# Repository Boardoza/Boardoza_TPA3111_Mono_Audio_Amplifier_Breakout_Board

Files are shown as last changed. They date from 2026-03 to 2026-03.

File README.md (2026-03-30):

# Boardoza TPA3111 Mono Audio Amplifier Breakout Board

The **Boardoza TPA3111 Mono Audio Amplifier Module** is a compact and efficient Class-D audio amplifier built around the **Texas Instruments TPA3111D1** chip. Designed to deliver up to **10W mono output power**, this board provides high-quality audio performance with minimal heat generation thanks to its high-efficiency architecture.

With a wide **8V to 28V DC input voltage range**, this amplifier module is compatible with a variety of power sources including DC adapters and battery systems. Screw terminal connections for power, audio input, and speaker output make installation quick and reliable. It is ideal for **DIY speaker builds, portable audio systems, embedded audio solutions, and custom sound projects** requiring compact and efficient amplification.

## [Click here to purchase!](https://www.ozdisan.com/ureticiler/boardoza)

| Front Side | Back Side |
|:---:|:---:|
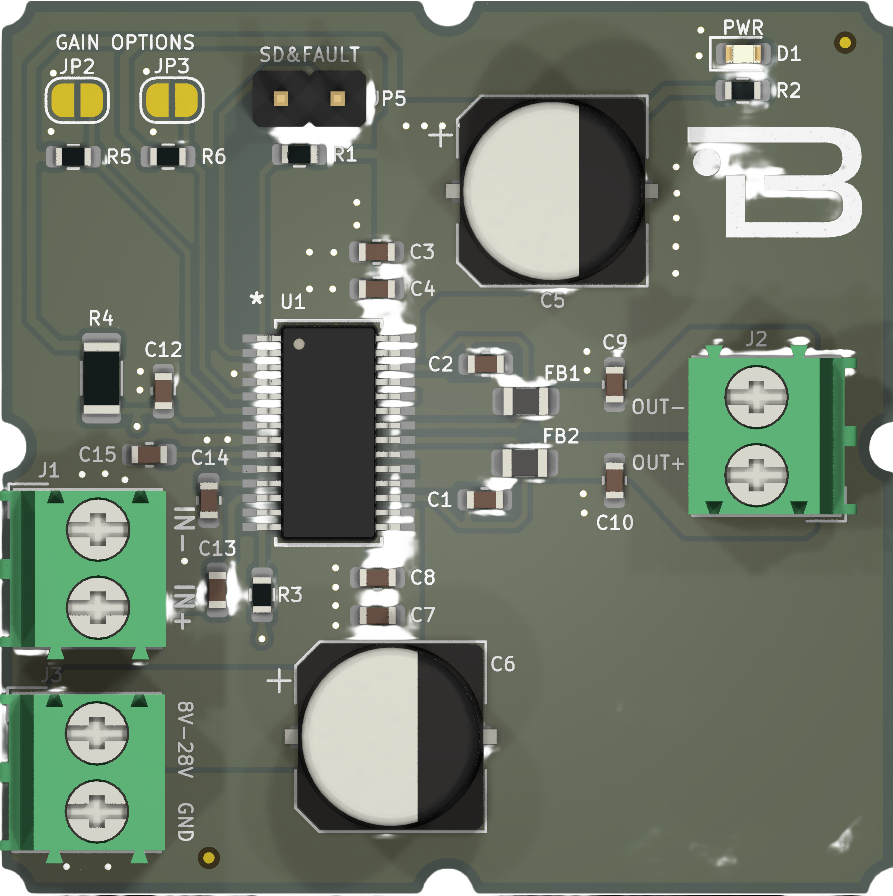
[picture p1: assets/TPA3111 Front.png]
TPA3111 Front
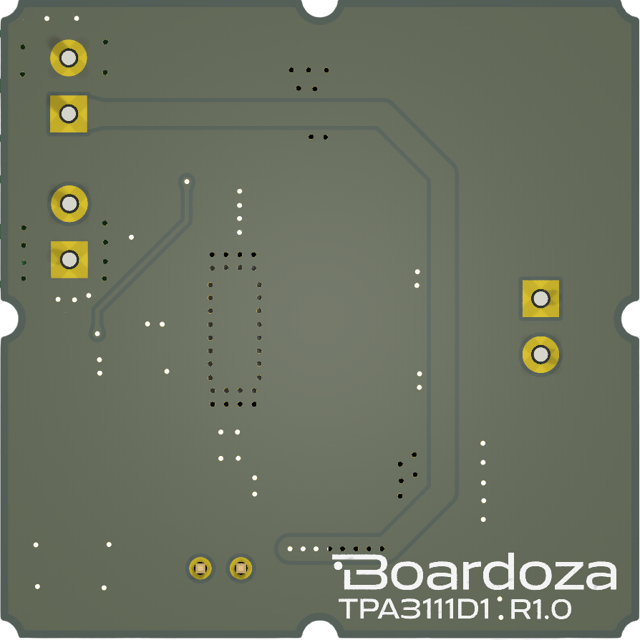
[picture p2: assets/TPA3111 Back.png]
TPA3111 Back
|  |  |

---

## Key Features

- **High-Efficiency Class-D Amplifier:** 310 khz Switching frequency provides clear and powerful mono audio output with minimal heat generation.
- **Wide Input Voltage Range:** Operates from 8V to 28V DC, compatible with various power sources.
- **Easy Connectivity:** Screw terminals for audio input, speaker output, and power connections.
- **Clean Audio Performance:** Integrated pop and click suppression for smooth startup and shutdown.
- **Built-in Protection Features:** Includes thermal shutdown and short-circuit protection for reliable operation.

---

## Technical Specifications

**Model:** TPA3111D1  
**Manufacturer:** Boardoza   
**Manufacturer IC:** Texas Instruments   
**Input Voltage:** 8V – 28V DC  
**Functions:** Mono Audio Amplifier  
**Amplifier Type:** Class-D  
**Output Power:** Up to 10W  
**Efficiency:** Up to 90%  
**Audio Output:** Mono (H-Bridge)  
**Gain Setting:** Configurable via JP2 / JP3 (Default: 36 dB)  
**Protection Features:** Thermal protection, short-circuit protection  
**Operating Temperature:** -40 °C to +85 °C  
**Board Dimensions:** 40 mm x 40 mm  

---

## Board Pinout

### **( JP2 & JP3 ) Gain Configuration (GAIN1 / GAIN0)**

| Pin / Jumper | Pin Name | Description |
|:---:|:---:|---|
| JP2 | GAIN1 | Gain select input (logic level via jumper) |
| JP3 | GAIN0 | Gain select input (logic level via jumper) |

> Default configuration is typically **36 dB** (GAIN1=1, GAIN0=1).

#### **Gain / Input Impedance Selection Table**

| GAIN1 | GAIN0 | Amplifier Gain (dB) (Typical) | Input Impedance (kΩ) (Typical) |
|:---:|:---:|:---:|:---:|
| 0 | 0 | 20 | 60 |
| 0 | 1 | 26 | 30 |
| 1 | 0 | 32 | 15 |
| 1 | 1 | 36 | 9 |

---

### **( JP5 ) Control Pins**

| Pin Number | Pin Name | Description |
|:---:|:---:|---|
| 1 | SD | Shutdown pin (Active Low). Connect to FAULT for auto-recovery |
| 2 | FAULT | Fault indicator pin (Active Low). Connect to SD for auto-recovery |

---

### **( J3 ) Power Connector**

| Pin Number | Pin Name | Description |
|:---:|:---:|---|
| 1 | 8V–28V | DC Voltage Input |
| 2 | GND | Ground |

---

### **( J1 ) Audio Input**

| Pin Number | Pin Name | Description |
|:---:|:---:|---|
| 1 | IN+ | Positive audio input |
| 2 | IN- | Negative audio input |

---

### **( J2 ) Speaker Output**

| Pin Number | Pin Name | Description |
|:---:|:---:|---|
| 1 | OUT+ | Class-D H-Bridge positive output |
| 2 | OUT- | Class-D H-Bridge negative output |

---

## Board Dimensions

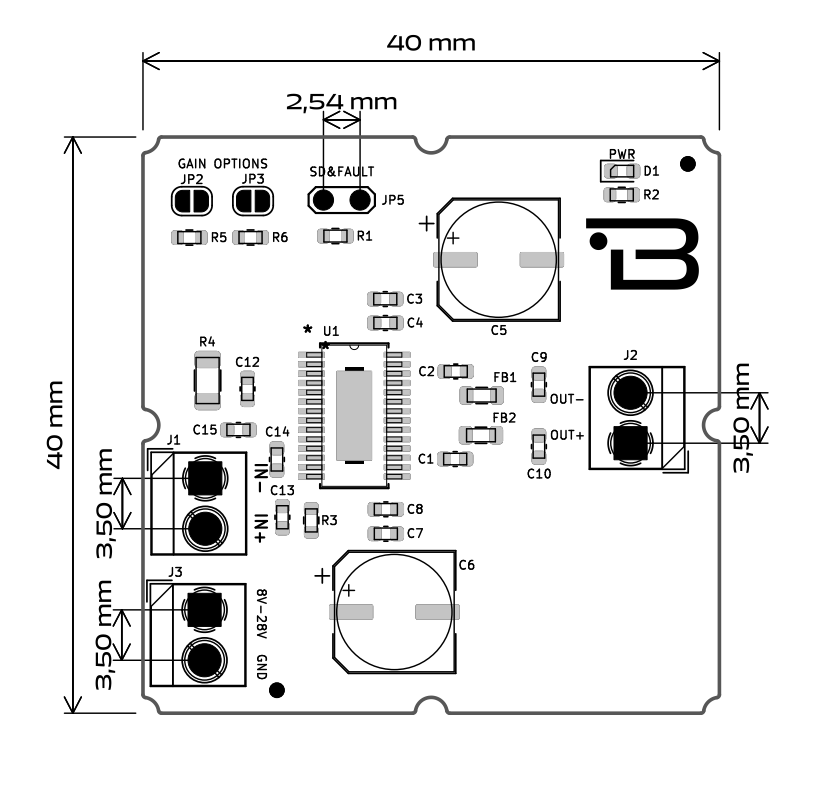
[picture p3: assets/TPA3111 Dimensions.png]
TPA3111 Board Dimensions


---

## Step Files

[Boardoza TPA3111.step](./assets/TPA3111%20Step.step)

---

## Datasheet

[TPA3111D1 Datasheet](./assets/TPA3111%20Datasheet.pdf)

---

## Version History

- **V1.0.0** – Initial Release

---

## Support

- If you have any questions or need support, please contact **support@boardoza.com**

---

## **License**
### **Hardware Design**

[][cc-by-sa]

All hardware design files are licensed under [Creative Commons Attribution-ShareAlike 4.0 International License][cc-by-sa].

[cc-by-sa]: http://creativecommons.org/licenses/by-sa/4.0/
[cc-by-sa-shield]: https://img.shields.io/badge/License-CC%20BY--SA%204.0-lightgrey.svg

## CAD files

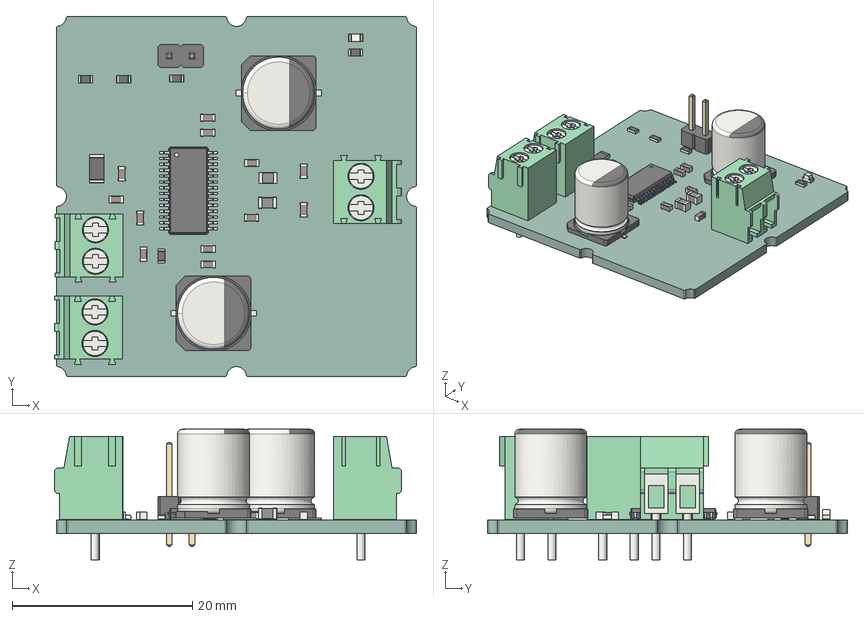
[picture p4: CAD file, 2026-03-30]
assets/TPA3111 Step.step
40.2 x 40.0 x 14.5 mm
C_0603_1608Metric x 12
CP_Elec_8x10 x 2
R_0603_1608Metric x 5
TerminalBlock_Phoenix_PT-1,5-2-3.5-H_1x02_P3.50mm_Horizontal x 3
R_1206_3216Metric
PinHeader_1x02_P2.54mm_Vertical
L_0805_2012Metric x 2
HTSSOP-28-1EP_4.4x9.7mm_P0.65mm_EP3.4x9.5mm
LED_0603_1608Metric
B-TPA3111-BRK_PCB

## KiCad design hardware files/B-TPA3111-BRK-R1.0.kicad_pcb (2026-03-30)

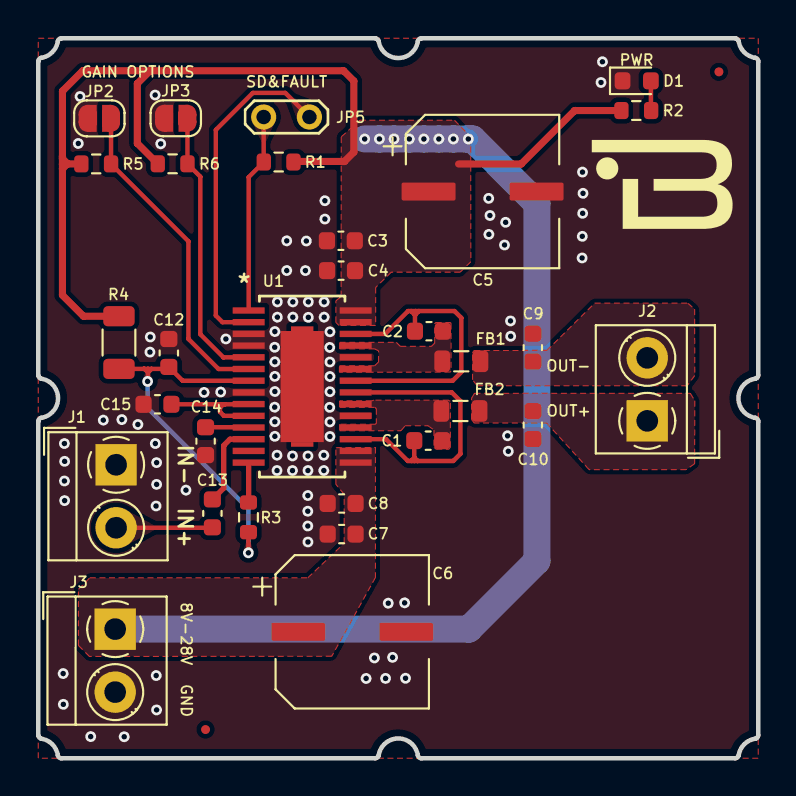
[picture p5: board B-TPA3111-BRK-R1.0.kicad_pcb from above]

Board: 2 copper layers, 40.0 x 40.0 mm, 30 parts (0 on the bottom side), 19 nets.

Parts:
C1, C2: 0.47uF; C_0603_1608Metric
C3, C7: 0.1uF; C_0603_1608Metric
C4, C8, C9, C10: 1000pF; C_0603_1608Metric
C5, C6: 100uF; CP_Elec_8x10
C12, C13, C14, C15: 1uF; C_0603_1608Metric
D1: RED; LED_0603_1608Metric
FB1, FB2: 120R/100MHz; L_0805_2012Metric
J1, J2, J3: Screw_Terminal_01x02; TerminalBlock_MetzConnect_Type059_RT06302HBWC_1x02_P3.50mm_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
JP2, JP3: SolderJumper_2_Open; SolderJumper-2_P1.3mm_Open_RoundedPad1.0x1.5mm
JP5: Jumper_2_Open; TestPoint_2Pads_Pitch2.54mm_Drill0.8mm
R1, R3, R5, R6: 100K; R_0603_1608Metric
R2: 3K; R_0603_1608Metric
R4: 10R; R_1206_3216Metric
U1: TPA3111D1PWPR; PWP28_6P17X2P4-M

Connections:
/AVCC: C12.1, R3.1, R4.2, U1.7 (AVCC)
/GAIN0: JP3.1 (A), R6.1, U1.5 (GAIN0)
/GAIN1: JP2.1 (A), R5.1, U1.6 (GAIN1)
/GVDD: C15.1, U1.9 (GVDD), U1.10 (PLIMIT)
/INP: C13.2, U1.12 (INP)
/OUT+: C10.1, FB2.2, J2.1
/OUT-: C9.2, FB1.2, J2.2
/PVCC: C3.1, C4.1, C5.1, C6.1, C7.1, C8.1, J3.1, R1.1, R2.2, R4.1, R5.2, R6.2, U1.15 (PVCC), U1.16 (PVCC), U1.27 (PVCC), U1.28 (PVCC)
GND: C3.2, C4.2, C5.2, C6.2, C7.2, C8.2, C9.1, C10.2, C12.2, C14.1, C15.2, D1.1 (K), J1.1, J3.2, JP2.2 (B), JP3.2 (B), U1.3 (GND), U1.4 (GND), U1.8 (AGND), U1.19 (PGND), U1.24 (PGND), U1.29 (EPAD)
unnamed: C1.1, FB2.1, U1.18 (OUTP), U1.20 (OUTP)
unnamed: C1.2, U1.17 (BSP), U1.21 (BSP)
unnamed: C2.1, FB1.1, U1.23 (OUTN), U1.25 (OUTN)
unnamed: C2.2, U1.22 (BSN), U1.26 (BSN)
unnamed: D1.2 (A), R2.1
unnamed: C13.1, J1.2
unnamed: JP5.1 (A), U1.2 (*FAULT)
unnamed: JP5.2 (B), R1.2, U1.1 (*SD)
unnamed: R3.2, U1.14 (AVCC)
unnamed: C14.2, U1.11 (INN)

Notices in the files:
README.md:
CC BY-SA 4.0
